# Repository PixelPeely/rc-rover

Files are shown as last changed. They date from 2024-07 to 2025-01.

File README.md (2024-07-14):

# rc-rover
Arduino-powered rc rover with live video feed

# Controller
## Custom circuit board:
The Controller PCB is responsible for charging a LiCD battery, as well as powering the screen board, which is an independent unit. The board contains through holes for the NRF24L01+ module, along with 4 LMS-5161 common anode 7 segment displays that are controlled by 4 74HC595 8-bit shift registers, all of which are controlled by an arduino nano every and powered by the LiCD battery.
Schematic:
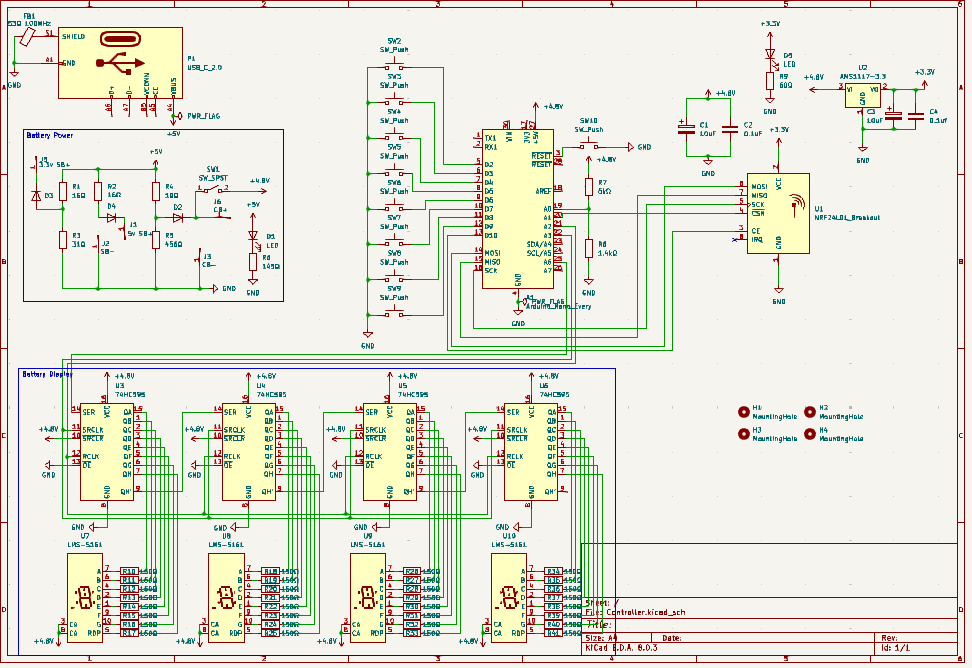
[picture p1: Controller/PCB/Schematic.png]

Footprint:
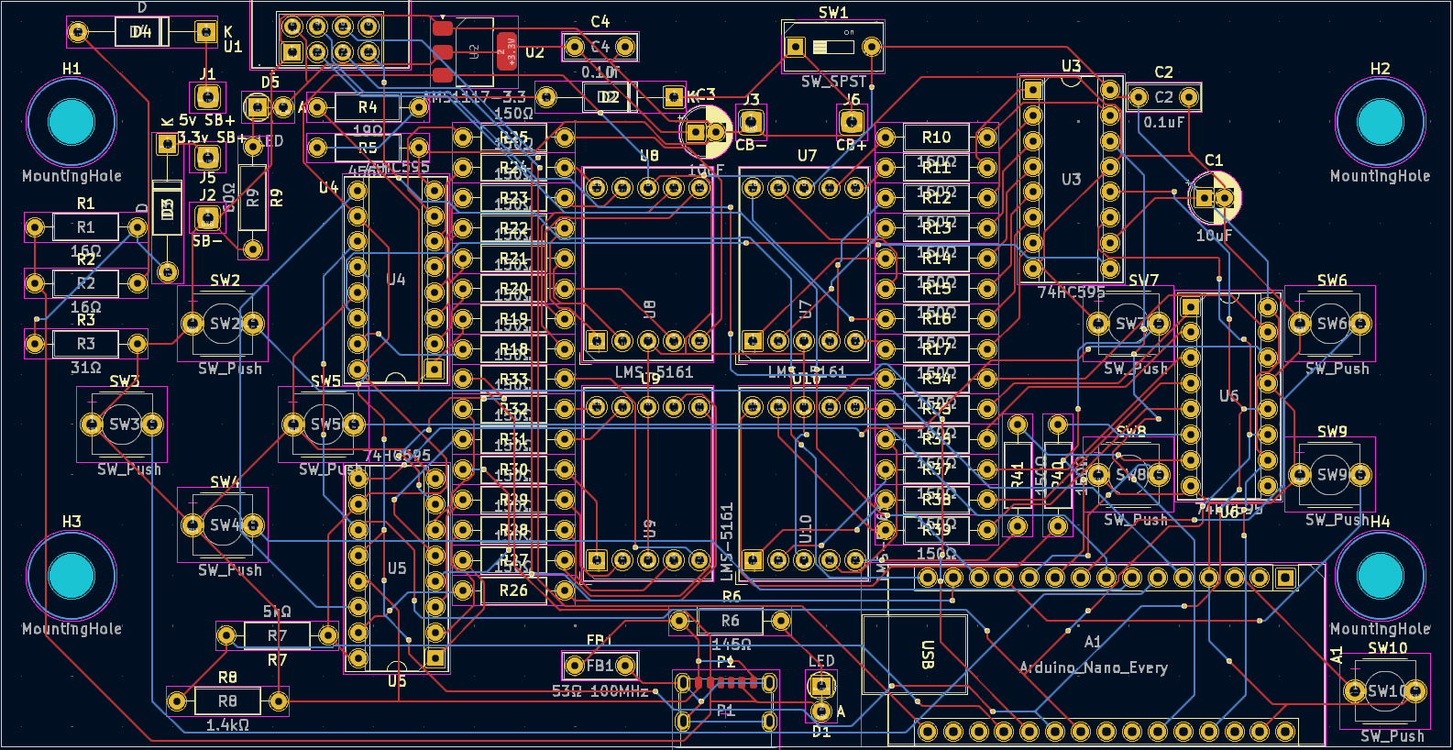
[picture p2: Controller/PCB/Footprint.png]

3D Render:
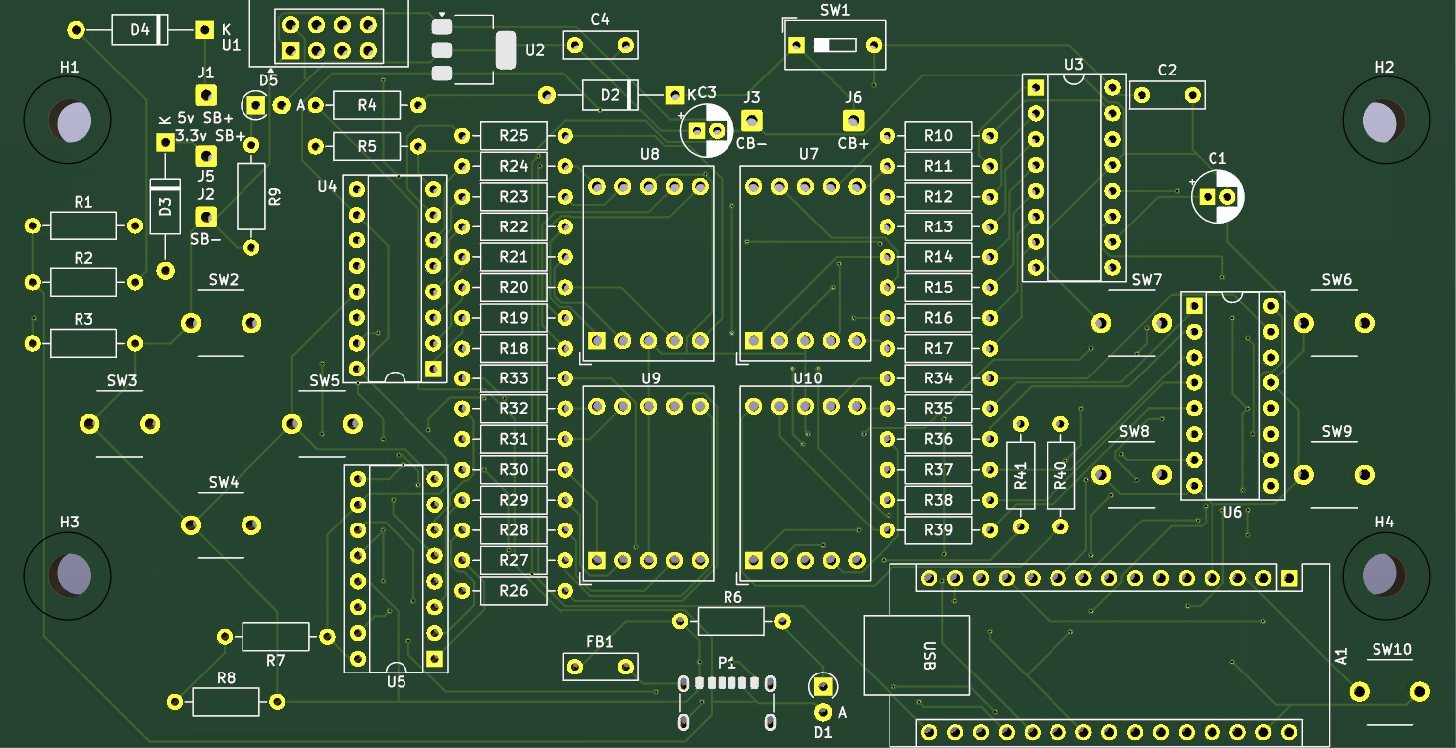
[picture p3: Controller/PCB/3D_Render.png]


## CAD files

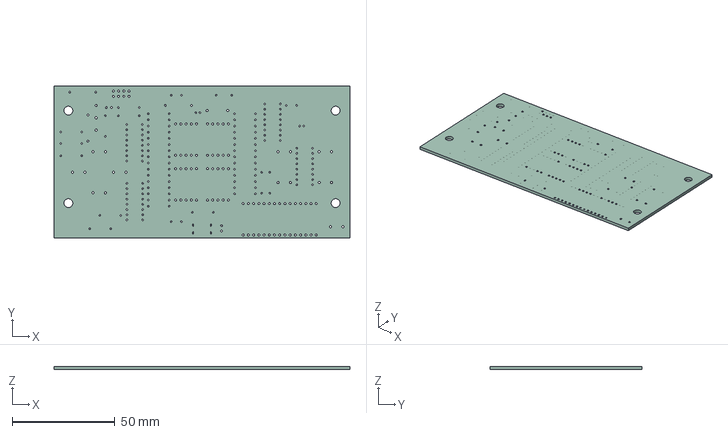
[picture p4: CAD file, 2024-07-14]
Controller/PCB/Controller.step
144.0 x 74.0 x 1.60 mm

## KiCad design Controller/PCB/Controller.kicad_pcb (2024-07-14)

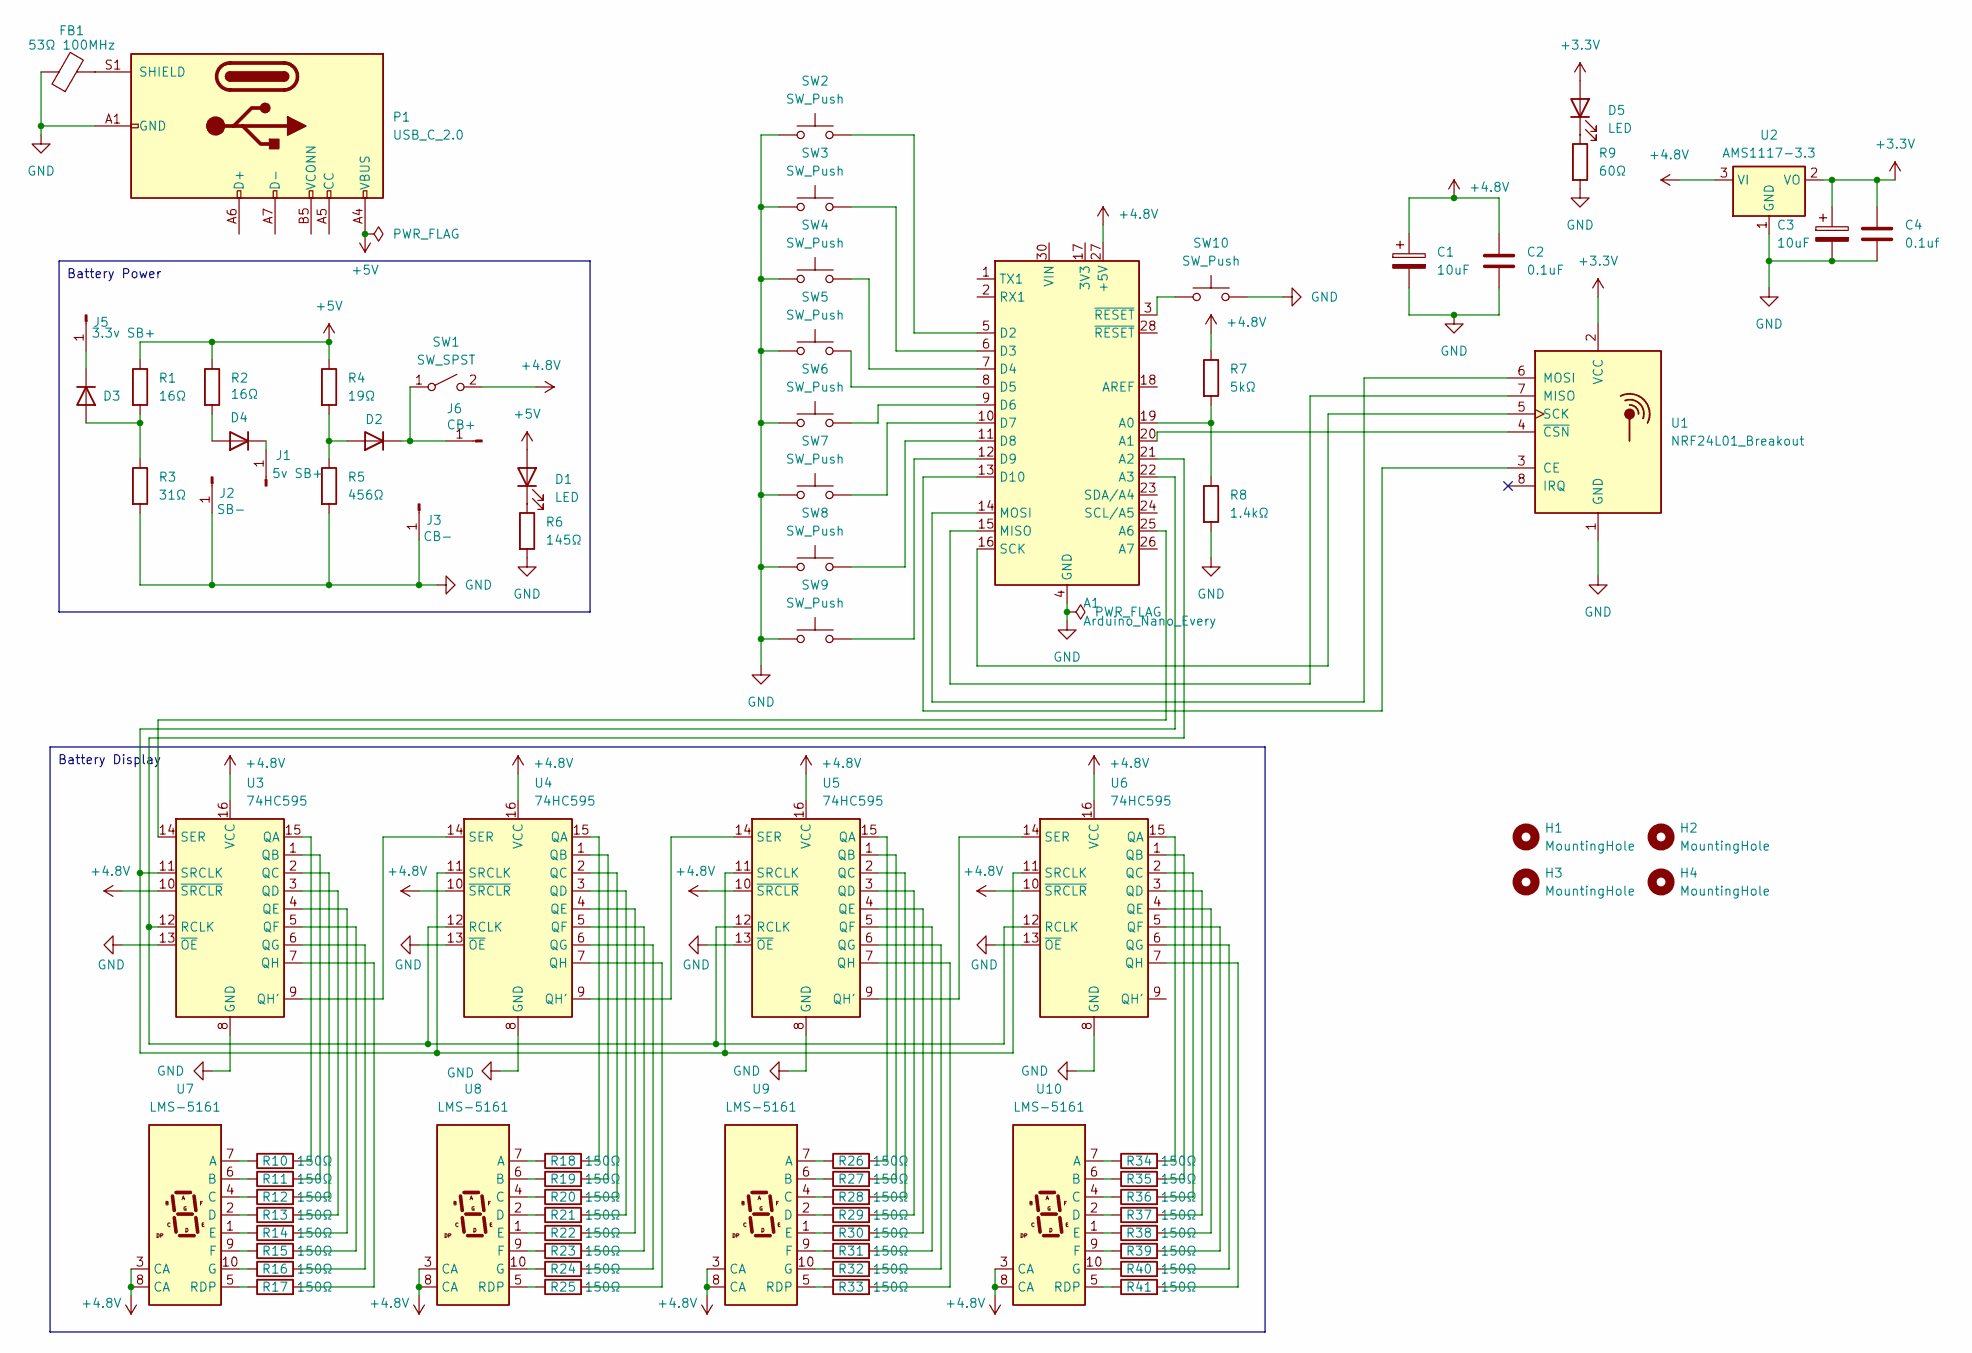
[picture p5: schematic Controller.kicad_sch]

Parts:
A1: Arduino_Nano_Every; Arduino_Nano
C1, C3: 10uF; CP_Radial_D5.0mm_P2.00mm
C2: 0.1uF; C_Rect_L7.2mm_W2.5mm_P5.00mm_FKS2_FKP2_MKS2_MKP2
C4: 0.1uf; C_Rect_L7.2mm_W2.5mm_P5.00mm_FKS2_FKP2_MKS2_MKP2
D1, D5: LED; D_A-405_P2.54mm_Vertical_AnodeUp
D2, D3, D4: D; D_A-405_P12.70mm_Horizontal
FB1: 53Ω 100MHz; C_Rect_L7.2mm_W2.5mm_P5.00mm_FKS2_FKP2_MKS2_MKP2
H1, H2, H3, H4: MountingHole; MountingHole_4.3mm_M4
J1: 5v SB+; SolderWire-0.5sqmm_1x01_D0.9mm_OD2.1mm
J2: SB-; SolderWire-0.5sqmm_1x01_D0.9mm_OD2.1mm
J3: CB-; SolderWire-0.5sqmm_1x01_D0.9mm_OD2.1mm
J5: 3.3v SB+; SolderWire-0.5sqmm_1x01_D0.9mm_OD2.1mm
J6: CB+; SolderWire-0.5sqmm_1x01_D0.9mm_OD2.1mm
P1: USB_C_2.0; USB_C_Receptacle_GCT_USB4125-xx-x_6P_TopMnt_Horizontal
R1, R2: 16Ω; R_Axial_DIN0207_L6.3mm_D2.5mm_P10.16mm_Horizontal
R3: 31Ω; R_Axial_DIN0207_L6.3mm_D2.5mm_P10.16mm_Horizontal
R4: 19Ω; R_Axial_DIN0207_L6.3mm_D2.5mm_P10.16mm_Horizontal
R5: 456Ω; R_Axial_DIN0207_L6.3mm_D2.5mm_P10.16mm_Horizontal
R6: 145Ω; R_Axial_DIN0207_L6.3mm_D2.5mm_P10.16mm_Horizontal
R7: 5kΩ; R_Axial_DIN0207_L6.3mm_D2.5mm_P10.16mm_Horizontal
R8: 1.4kΩ; R_Axial_DIN0207_L6.3mm_D2.5mm_P10.16mm_Horizontal
R9: 60Ω; R_Axial_DIN0207_L6.3mm_D2.5mm_P10.16mm_Horizontal
R10, R11, R12, R13, R14, R15, R16, R17, R18, R19, R20, R21, R22, R23, R24, R25, R26, R27, R28, R29, R30, R31, R32, R33, R34, R35, R36, R37, R38, R39, R40, R41: 150Ω; R_Axial_DIN0207_L6.3mm_D2.5mm_P10.16mm_Horizontal
SW1: SW_SPST; SW_DIP_SPSTx01_Slide_9.78x4.72mm_W7.62mm_P2.54mm
SW2, SW3, SW4, SW5, SW6, SW7, SW8, SW9, SW10: SW_Push; SW_PUSH_Singular_6mm
U1: NRF24L01_Breakout; nRF24L01_Antenna
U2: AMS1117-3.3; SOT-223-3_TabPin2
U3, U4, U5, U6: 74HC595; DIP-16_W7.62mm_Socket
U7, U8, U9, U10: LMS-5161

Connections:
+3.3V: C3.1, C4.1, D5.2 (A), U1.2 (VCC), U2.2 (VO)
+4.8V: A1.27 (+5V), C1.1, C2.1, R7.1, SW1.2 (B), U2.3 (VI), U3.10 (~SRCLR), U3.16 (VCC), U4.10 (~SRCLR), U4.16 (VCC), U5.10 (~SRCLR), U5.16 (VCC), U6.10 (~SRCLR), U6.16 (VCC), U7.3 (CA), U7.8 (CA), U8.3 (CA), U8.8 (CA), U9.3 (CA), U9.8 (CA), U10.3 (CA), U10.8 (CA)
+5V: D1.2 (A), P1.A4 (VBUS), P1.A9 (VBUS), P1.B4 (VBUS), P1.B9 (VBUS), R1.1, R2.1, R4.1
GND: A1.4 (GND), A1.29 (GND), C1.2, C2.2, C3.2, C4.2, FB1.1, J2.1, J3.1, P1.A1 (GND), P1.A12 (GND), P1.B1 (GND), P1.B12 (GND), R3.2, R5.2, R6.2, R8.2, R9.2, SW2.1, SW3.1, SW4.1, SW5.1, SW6.1, SW7.1, SW8.1, SW9.1, SW10.2, U1.1 (GND), U2.1 (GND), U3.8 (GND), U3.13 (~OE), U4.8 (GND), U4.13 (~OE), U5.8 (GND), U5.13 (~OE), U6.8 (GND), U6.13 (~OE)
unnamed: A1.19 (A0), R7.2, R8.1
unnamed: A1.20 (A1), U1.4 (~CSN)
unnamed: A1.21 (A2), U3.12 (RCLK), U4.12 (RCLK), U5.12 (RCLK), U6.12 (RCLK)
unnamed: A1.22 (A3), U3.11 (SRCLK), U4.11 (SRCLK), U5.11 (SRCLK), U6.11 (SRCLK)
unnamed: A1.25 (A6), U3.14 (SER)
unnamed: A1.5 (D2), SW2.2
unnamed: A1.6 (D3), SW3.2
unnamed: A1.7 (D4), SW4.2
unnamed: A1.8 (D5), SW5.2
unnamed: A1.9 (D6), SW6.2
unnamed: A1.10 (D7), SW7.2
unnamed: A1.11 (D8), SW8.2
unnamed: A1.12 (D9), SW9.2
unnamed: A1.13 (D10), U1.3 (CE)
unnamed: A1.15 (MISO), U1.7 (MISO)
unnamed: A1.14 (MOSI), U1.6 (MOSI)
unnamed: A1.16 (SCK), U1.5 (SCK)
unnamed: A1.3 (~RESET), SW10.1
unnamed: D1.1 (K), R6.1
unnamed: D2.2 (A), R4.2, R5.1
unnamed: D2.1 (K), J6.1, SW1.1 (A)
unnamed: D3.2 (A), R1.2, R3.1
unnamed: D3.1 (K), J5.1
unnamed: D4.2 (A), R2.2
unnamed: D4.1 (K), J1.1
unnamed: D5.1 (K), R9.1
unnamed: FB1.2, P1.S1 (SHIELD)
unnamed: R10.2, U3.15 (QA)
unnamed: R11.2, U3.1 (QB)
unnamed: R12.2, U3.2 (QC)
unnamed: R13.2, U3.3 (QD)
unnamed: R14.2, U3.4 (QE)
unnamed: R15.2, U3.5 (QF)
unnamed: R16.2, U3.6 (QG)
unnamed: U3.9 (QH'), U4.14 (SER)
unnamed: R17.2, U3.7 (QH)
unnamed: R18.2, U4.15 (QA)
unnamed: R19.2, U4.1 (QB)
unnamed: R20.2, U4.2 (QC)
unnamed: R21.2, U4.3 (QD)
unnamed: R22.2, U4.4 (QE)
unnamed: R23.2, U4.5 (QF)
unnamed: R24.2, U4.6 (QG)
unnamed: U4.9 (QH'), U5.14 (SER)
unnamed: R25.2, U4.7 (QH)
unnamed: R26.2, U5.15 (QA)
unnamed: R27.2, U5.1 (QB)
unnamed: R28.2, U5.2 (QC)
unnamed: R29.2, U5.3 (QD)
unnamed: R30.2, U5.4 (QE)
unnamed: R31.2, U5.5 (QF)
unnamed: R32.2, U5.6 (QG)
unnamed: U5.9 (QH'), U6.14 (SER)
unnamed: R33.2, U5.7 (QH)
unnamed: R34.2, U6.15 (QA)
unnamed: R35.2, U6.1 (QB)
unnamed: R36.2, U6.2 (QC)
unnamed: R37.2, U6.3 (QD)
unnamed: R38.2, U6.4 (QE)
unnamed: R39.2, U6.5 (QF)
unnamed: R40.2, U6.6 (QG)
unnamed: R41.2, U6.7 (QH)
unnamed: R10.1, U7.7 (A)
unnamed: R11.1, U7.6 (B)
unnamed: R12.1, U7.4 (C)
unnamed: R13.1, U7.2 (D)
unnamed: R14.1, U7.1 (E)
unnamed: R15.1, U7.9 (F)
unnamed: R16.1, U7.10 (G)
unnamed: R17.1, U7.5 (RDP)
unnamed: R18.1, U8.7 (A)
unnamed: R19.1, U8.6 (B)
unnamed: R20.1, U8.4 (C)
unnamed: R21.1, U8.2 (D)
unnamed: R22.1, U8.1 (E)
unnamed: R23.1, U8.9 (F)
unnamed: R24.1, U8.10 (G)
unnamed: R25.1, U8.5 (RDP)
unnamed: R26.1, U9.7 (A)
unnamed: R27.1, U9.6 (B)
unnamed: R28.1, U9.4 (C)
unnamed: R29.1, U9.2 (D)
unnamed: R30.1, U9.1 (E)
unnamed: R31.1, U9.9 (F)
unnamed: R32.1, U9.10 (G)
unnamed: R33.1, U9.5 (RDP)
unnamed: R34.1, U10.7 (A)
unnamed: R35.1, U10.6 (B)
unnamed: R36.1, U10.4 (C)
unnamed: R37.1, U10.2 (D)
unnamed: R38.1, U10.1 (E)
unnamed: R39.1, U10.9 (F)
unnamed: R40.1, U10.10 (G)
unnamed: R41.1, U10.5 (RDP)

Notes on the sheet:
Battery Display
Battery Power

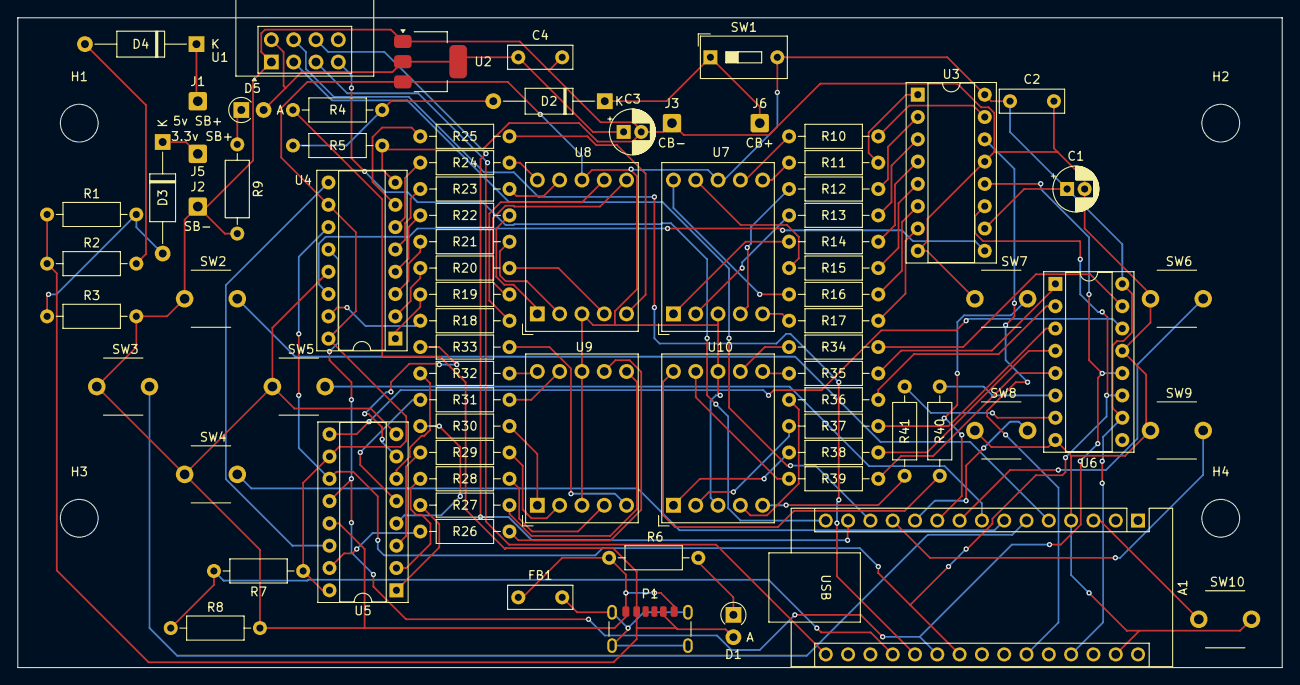
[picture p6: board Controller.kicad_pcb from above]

Board: 2 copper layers, 144.0 x 74.0 mm, 82 parts (0 on the bottom side), 98 nets.

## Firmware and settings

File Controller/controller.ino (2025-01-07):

#include <SPI.h>
#include "RF24.h"
//Solder breakout board to main power supply
#define PIN_CS_RADIO 10
#define PIN_CSN_RADIO A1



#define SHIFT_SER A6
#define SHIFT_SRCLK A3
#define SHIFT_RCLK A2
const uint8_t digit_buf[] = {
  0b11111100,
  0b01100000,
  0b11011010,
  0b11110010,
  0b01100110,
  0b10110110,
  0b10111110,
  0b11100000,
  0b11111110,
  0b11110110,
  0b00000001,
  0b11101100,//n
  0b10011100,//c
};

#define BATTERY_SENSE A0
#define FULL_ANALOG 1000
#define DEPLETED_ANALOG 500
#define DISPLAY_SENSITIVITY 0.001

const byte NRF24_RADIO_ADDRESS[][6] = {"00001", "00002"};
RF24 NRF24_RADIO(PIN_CS_RADIO, PIN_CSN_RADIO);
#define PAYLOAD_INPUT 0x00
#define PAYLOAD_DIAGNOSE 0x01

inline void init_NRF24_RADIO() {
  Serial.println("Initializing NRF24_RADIO");
  Serial.println("-Begin success flag: " + String(NRF24_RADIO.begin()));
  delay(100);
  NRF24_RADIO.setPALevel(RF24_PA_LOW);
  NRF24_RADIO.setPayloadSize(sizeof(uint8_t));
  NRF24_RADIO.enableAckPayload();
  NRF24_RADIO.openWritingPipe(NRF24_RADIO_ADDRESS[0]);
  NRF24_RADIO.openReadingPipe(1, NRF24_RADIO_ADDRESS[1]);
  NRF24_RADIO.stopListening();
  Serial.println("-Set config");
}

inline void init_input() {
  for (uint8_t i = 0; i < 8; i++)
    pinMode(i+2, INPUT_PULLUP);
}

inline void init_reg() {
  pinMode(SHIFT_SER, OUTPUT);
  pinMode(SHIFT_SRCLK, OUTPUT);
  pinMode(SHIFT_RCLK, OUTPUT);
}

bool send_input() {
  uint8_t input = ~(digitalRead(2) << 7 | digitalRead(3) << 6 | digitalRead(4) << 5 | digitalRead(5) << 4 | digitalRead(6) << 3 | digitalRead(7) << 2 | digitalRead(8) << 1 | digitalRead(9));
  //Serial.println("Transmitting " + String(input));
  NRF24_RADIO.flush_tx();
  return NRF24_RADIO.write(&input, sizeof(uint8_t));
}

void setup() {
  Serial.begin(115200);
  Serial.println("Begin controller 115200");
  init_NRF24_RADIO();
  init_input();
  init_reg();
  analogReference(INTERNAL1V1);
  Serial.println("Setup complete");
}

uint8_t rover_battery = 0xFF;
uint8_t controller_battery = 0xFF;
float intermediate = 0xFFFF;
void loop() {
  delay(50);
  if (send_input() && NRF24_RADIO.available()) {
    NRF24_RADIO.read(&rover_battery, sizeof(uint8_t));
    NRF24_RADIO.flush_rx();
  } else rover_battery = 0xFF;

  float analog_reading = ((float)analogRead(BATTERY_SENSE) - DEPLETED_ANALOG) / (FULL_ANALOG - DEPLETED_ANALOG) * 100;
  if (intermediate == 0xFFFF) intermediate = analog_reading;
  intermediate += (analog_reading - intermediate) * DISPLAY_SENSITIVITY;
  if (intermediate < 0) intermediate = 0;
  else if (intermediate > 100) intermediate = 100;
  if (intermediate > controller_battery + 2) controller_battery = (uint8_t)intermediate;
  if (intermediate < controller_battery) controller_battery = (uint8_t)intermediate;
  if (abs(analog_reading - controller_battery) > 25) controller_battery = intermediate = analog_reading;
  update_battery_display(controller_battery, rover_battery);
}

void update_battery_display(uint8_t controller_battery, uint8_t rover_battery) {
  uint8_t controller_digit1 = controller_battery / 10;
  uint8_t controller_digit2 = controller_battery - controller_digit1 * 10;
  uint8_t rover_digit1 = rover_battery / 10;
  uint8_t rover_digit2 = rover_battery - rover_digit1 * 10;

  if (rover_battery == 0xFF) {
    rover_digit1 = 11;
    rover_digit2 = 12;
  }

  digitalWrite(SHIFT_RCLK, LOW);
  shiftOut(SHIFT_SER, SHIFT_SRCLK, LSBFIRST, ~digit_buf[controller_digit2]);
  shiftOut(SHIFT_SER, SHIFT_SRCLK, LSBFIRST, ~digit_buf[controller_digit1]);
  shiftOut(SHIFT_SER, SHIFT_SRCLK, LSBFIRST, ~digit_buf[rover_digit1]);
  shiftOut(SHIFT_SER, SHIFT_SRCLK, LSBFIRST, ~digit_buf[rover_digit2]);
  digitalWrite(SHIFT_RCLK, HIGH);
}
